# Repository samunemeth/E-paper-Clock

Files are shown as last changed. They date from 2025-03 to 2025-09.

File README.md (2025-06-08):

> [!IMPORTANT]
> More features are hopefully coming soon!
>
> This repository is not even close to being finished.
> I will try to include all the files and useful resources,
> but there are a lot, so it will take time.

# E-paper Clock 

This is an e-paper clock based on a *WeAct Studio 2.9" BW* display,
and a custom *Info Station V6* mainboard.

## Current functionality

The clock can connect to a local network to get the time hen powered on.
After this, and internal timer is calibrated to the current timezone.
The display is refreshed every minute. Between the refreshes, the *ESP32-C3*
and the display enters deep sleep to preserve battery power.

At set hours, the clock
will resync to a time server, and it will show the last resync.
The clock can also monitor it's battery level.
By pressing the update button, the display is kept awake to 
be able to remain connected to a computer, and receive and update easily.
Pressing the top button enables seconds mode, witch shows the seconds for a set
amount of time, or until the button is pressed again.

Settings can be configures easily in the [`settings.h`](src/settings.h) file.
Descriptions and recommendations are written next to important options.

> [!NOTE]
> I try to document the code as much as I can, but if you have any questions,
> feel free to contact me.

## PCB

The current version used by the codebase is **V6**.

The PCB can be found in the *mainboard* folder.
There are also gerber files, specifically exported for production with
[*JLCPCB*](https://jlcpcb.com/).
If you just want to look at the schematic, you can use the pdf.

> [!NOTE]
> The main branch is using the **V6** motherboard.
> If you want to use a **V2** motherboard, check out the dedicated branch.

## Setup

  - Install *PlatformIO*.
  - Clone this repository to your local machine.
  - Copy the [`src/wifi_secret.h.outline`](src/wifi_secret.h.outline) file,
    and rename it to `src/wifi_secret.h`.
  - Enter your WiFi SSID *(network name)* and password,
    replacing the placeholder values in `src/wifi_secret.h`.
  - Change your port settings in the [`platformio.ini`](platformio.ini) file.
    You can also use auto port detection on windows but *not* on linux.
  - Select the correct environment for uploading:
    - With `platformio.run --environment YourEnvironment` on command line.
    - By selecting the correct folder in *VSCode*.
  - I recommend using the default settings for the first upload.
    After that, you can change the settings in the
    [`settings.h`](src/settings.h) file by commenting or uncommenting
    definitions, or by changing values. A short explanation of options
    are included in the file.

## ToDo

**Implement**
  - Add charging detection.
  - Add stopper mode.
  - Show wifi strength at last sync.
  - Multiple WiFi connections.
    *[More Info](https://randomnerdtutorials.com/esp32-wifimulti/)*
  - Skip resync if the wifi times out.
  - Better fonts, for example *Roboto*.
  - Switch to using precise time.

**Ideas**
  - Add hibernation for night? *(Basically just a longer deep sleep at night.)*
  - Indicate potential drift based on time from last sync.

**Test**
  - Check SNTP time documentation, if it only gets time once.
  - Test the three different internal, and external oscillators.
    *[More Info](https://docs.espressif.com/projects/esp-idf/en/stable/esp32c3/api-reference/system/system_time.html)*
  - Test power consumption with different configurations.
  - Ways to connect to WiFi faster, like storing the channel number, or setting
  up a persistent wifi connection.
  - ***GPIO4 can and will fuck with you!***

**Document**
  - Document the telemetry collection server.
  - Document the font creation process.
  - Document assembly and schematics.
  - Document 3D printed parts.

## Regarding the display

### Differences

After ordering multiple display panels from the same
[AliExpress listing](https://www.aliexpress.com/item/1005004644515880.html?spm=a2g0o.order_list.order_list_main.89.31de1802V2DEme),
I received two different kinds of display modules.
from the outside they look almost identical, apart from the part number
on the display ribbon cable. The older ones are marked *FPC-A005*, while
the newer ones are marked *FPC-7519rev.b*.
The displays have the same [documentation provided by WeAct Studio](https://github.com/WeActStudio/WeActStudio.EpaperModule/blob/master/Doc/ZJY128296-029EAAMFGN.pdf).

As they are both copies of similar displays, we have to take these numbers
with a grain of salt. The old one seems to be a copy (and simplification)
of a 3 color display, while the new one seems to be a copy (and again, 
simplification) of this
[Waveshare panel](https://www.waveshare.com/product/2.9inch-e-paper-module.htm).
While the old display lacks the third color, the new one is missing the
gray levels. *(Or at least, I could not get it to work...)*

After powering the on, the difference is obvious: the refresh times.
While the old display takes  around 4s to do a full refresh, the new one only
takes around 2s, and does not blink as much, making it a lot less distracting.
The new display does seem to loose quality faster when doing partial
refreshes.
For these reasons, I prefer partial refreshes on the old, and
full refreshes on the new display.

The new display also goes to hibernation, while the old one seems
to consume around 1mA. I am still testing this aspect.

Despite these differences, the communication and setup for the displays
are the same, they are a drop-in replacement for each other.

### Display health

As *WeAct Studio* does not provide any information regarding display health,
I will be referencing [Waveshare's display health information](https://www.waveshare.com/wiki/2.9inch_e-Paper_Module_Manual#Precautions)
for a very similar display.

It suggest full refreshing every *"several"* partial refreshes.
As *several* is not too exact, I would go with 5-10 partial refreshes for a
full refresh
However, after running one of the older displays for around 2 months with
only fast refreshes, I do not see any mayor degradation.

It also recommends a refresh interval of *"at least 180s"*.
That will not happen for a clock of course, but again I do not see
any particular reason this should affect the display in any negative way.

They also suggest powering down the display, or putting it in deep sleep.
This of course is done as soon as possible, and is an understandable
requirement.

## Design Choices

### Global SPI Port Remapping

As the default SPI pins on the *ESP32-C3 Supermini* are located in
locations unsuitable for this project, as they use important pins in
the RTC pin domain. These are the pins that can be used for wakeup
from deep sleep, and the pins that can be held during deep sleep.
As these pins are needed for other applications, we need to remap the
SPI pins to less important ones.

The port remapping is done by modifying the default `pins_arduino.h`
configuration file. Thankfully this can be done on a per-project basis.
The location of the configuration file is changed to the local one with
the  `board_build.variants_dir = variants` option.

To view the new pin configuration, check out the file:
[`pins_arduino.h`](variants/lolin_c3_mini/pins_arduino.h).

### Modes

Modes are stored in a `uint8_t`, and have constants with their names
and a `*_MODE` suffix.

| Mode Name: | NULL | RESET | NORMAL | RESYNC | SECONDS | STOPPER | UPDATE | CRITICAL |
| ---: | :---: | :---: | :---: | :---: | :---: | :---: | :---: | :---: |
| Decimal Value: | 0 | 1 | 2 | 4 | 8 | 16 | 32 | 64 |
| Bit shifted Value: | 0 | 1 << 0 | 1 << 1 | 1 << 2 | 1 << 3 | 1 << 4 | 1 << 5 | 1 << 6 |

### Timer Choice

The project is currently uses the *external* oscillator over the default
*RC* oscillator, or the internal *8MD256* oscillator.
This is presumably the middle gorund considering both
accuracy and power consumption.
The compromises are not yet fully clear to me,
*further testing and investigation is required*.

## Useful Resources

  - Purchase display:
    [AliExpress](https://www.aliexpress.com/item/1005004644515880.html?spm=a2g0o.order_list.order_list_main.89.31de1802V2DEme).
  - Library used for the display:
    [GxEPD2](https://github.com/ZinggJM/GxEPD2)
  - Sleep modes on the *ESP32-C3*:
    [Espressif Documentation](https://docs.espressif.com/projects/esp-idf/en/v5.4/esp32c3/api-reference/system/sleep_modes.html).
  - GPIO documentation:
    [Espressif Documentation](https://docs.espressif.com/projects/esp-idf/en/v5.1.4/esp32c3/api-reference/peripherals/gpio.html).
  - Showcasing the display and library:
    [Video](https://youtu.be/KZGjsC-JkR8?si=c3sMc7xT4hFs9A2L).
    And the code they used:
    [GitHub](https://github.com/devtales-official/screen-test/tree/main/devtales_screentest_ep2).
  - Generating new fonts:
    [Adafruit Documentation](https://learn.adafruit.com/adafruit-gfx-graphics-library/using-fonts).
    *(tl;dr: You pretty much must do this on linux.)*
  - How to remap global SPI ports:
    [Arduino Forum Thread](https://forum.arduino.cc/t/understanding-spi-pin-remapping-for-gxepd2-on-a-esp32-c3-mini/1065982).
    *(I looked 3 hours for this.)*
  - Advanced deep sleep wakeup functionality:
    [Espressif Documentation](https://docs.espressif.com/projects/esp-idf/en/stable/esp32c3/api-guides/deep-sleep-stub.html).
  - Deep sleep wakeup with gpio:
    [StackOverflow](https://stackoverflow.com/questions/76823215/deep-sleep-with-ext0-or-ext1-on-esp32-c3-mini-1).
  - Holding pins in deep sleep:
    [Reddit](https://www.reddit.com/r/esp32/comments/1dhh5ez/esp32c3_pin_goes_high_on_deep_sleep/).
  - ADC accuracy:
    [Link Tree](https://www.esp32.com/viewtopic.php?t=23902).
  - Built in adc calibration:
    [Reddit](https://www.reddit.com/r/esp32/comments/1dybanl/measuring_battery_levels/).
  - Estimating battery percentage from voltage:
    [Desmos](https://www.desmos.com/calculator/tfllnkhdcv),
    [Reference Data](https://blog.ampow.com/lipo-voltage-chart/).
  - Rebooting with persistent RTC memory:
    [Reddit](https://www.reddit.com/r/esp32/comments/qokk1z/reboot_without_losing_rtc_variables/).
  - ESP-C3 supermini pinout:
    [Arduino Forum Thread](https://forum.arduino.cc/t/esp32-c3-supermini-pinout/1189850/23).
  - Sub sleep levels:
    [Espressif Documentation](https://docs.espressif.com/projects/esp-idf/en/stable/esp32c3/api-reference/system/sleep_modes.html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).
  - Optimization:
    [Espressif Documentation](https://docs.espressif.com/projects/esp-idf/en/v5.2.5/esp32c3/api-guides/performance/speed.html)
  - Display driver:
    [Data Sheet](https://mikroshop.ch/pdf/EPaper29.pdf)
  - Online XBM editor:
    [Webpage](https://xbm.jazzychad.net)

## Ports, Future Updates

The display could be reasonably used with *Esphome*.
The configuration however is quite difficult, and the power efficiency will 
definitely be worse. I do not think I will be attempting to port it.
I already have code for a [similar project](#related-projects).

## Related Projects

The mainboard is borrowed from *Weather Station V1*.
The only hardware difference is the display,
as that project uses the 3 color version.
The software however is completely different, as that project uses *Esphome*.

After designing the new mainboard, I will be publishing more information
and configuration regarding that project, in a separate repo.

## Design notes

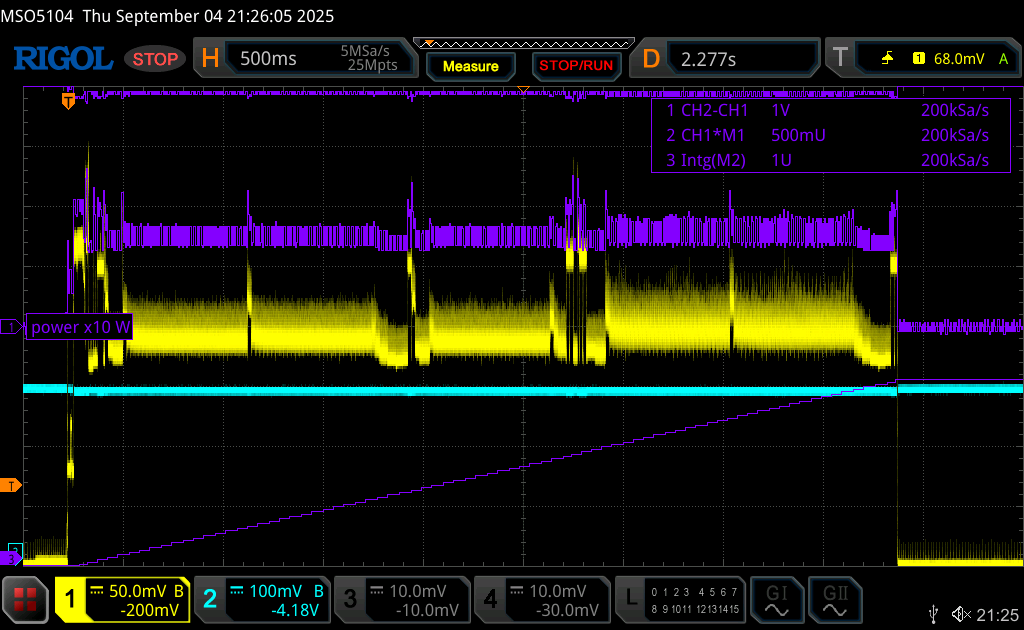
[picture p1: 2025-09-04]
collected-data/new-display-clear-refresh/graph.png

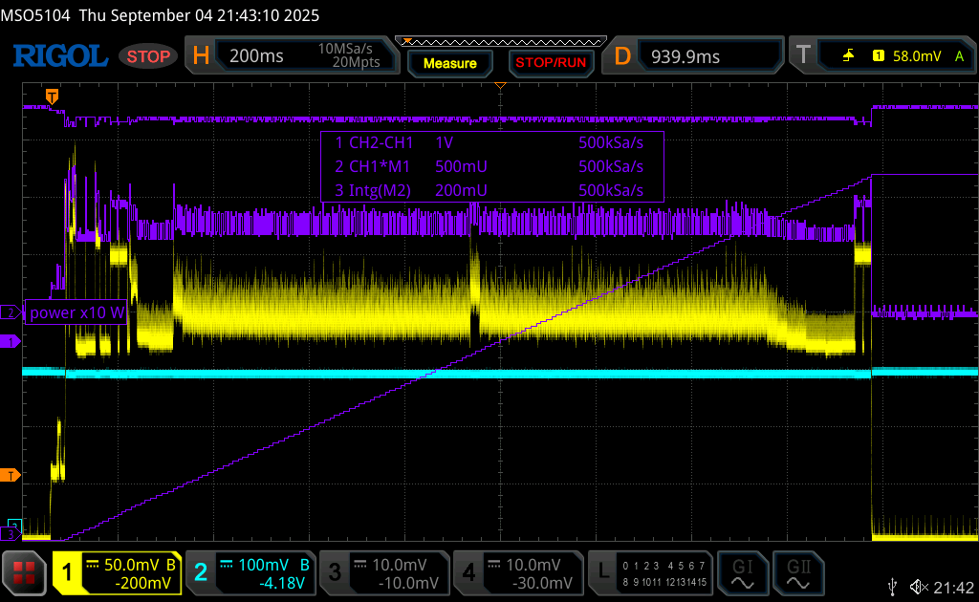
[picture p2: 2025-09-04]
collected-data/new-display-full-refresh/graph.png

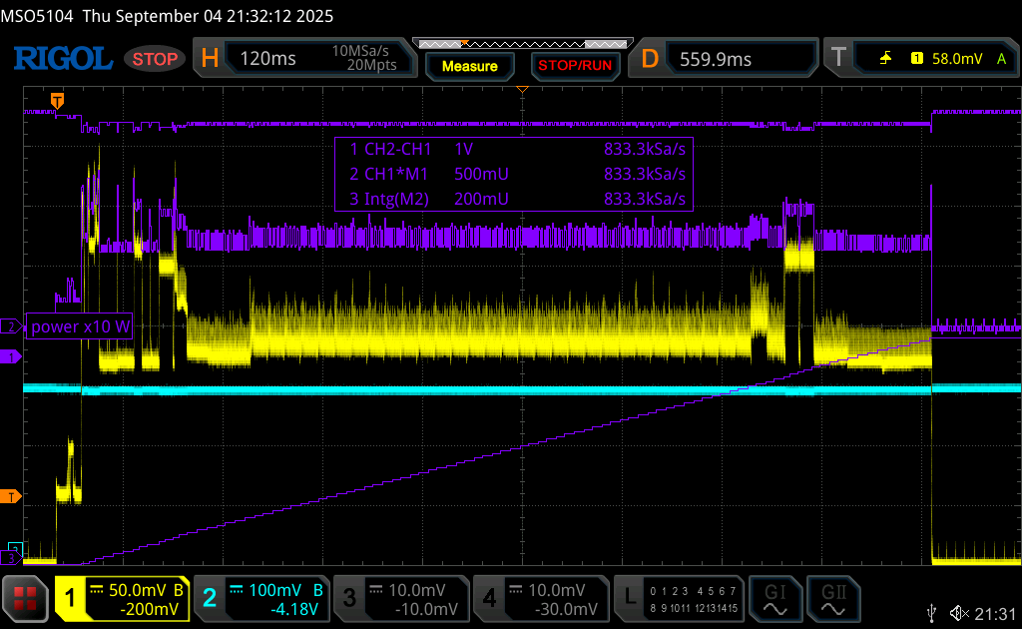
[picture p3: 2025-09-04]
collected-data/new-display-partial-refresh/graph.png

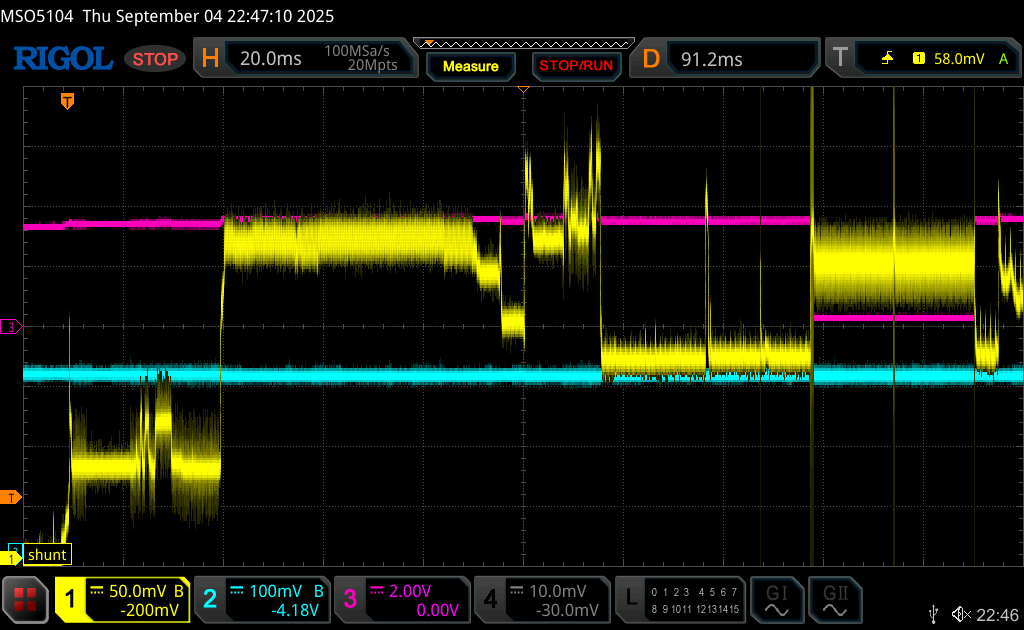
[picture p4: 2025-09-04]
collected-data/cs-signal.png

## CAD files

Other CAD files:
collected-data/new-display-clear-refresh/setup.stp
collected-data/new-display-full-refresh/setup.stp
collected-data/new-display-partial-refresh/setup.stp
collected-data/old-display-partial-refresh/setup.stp

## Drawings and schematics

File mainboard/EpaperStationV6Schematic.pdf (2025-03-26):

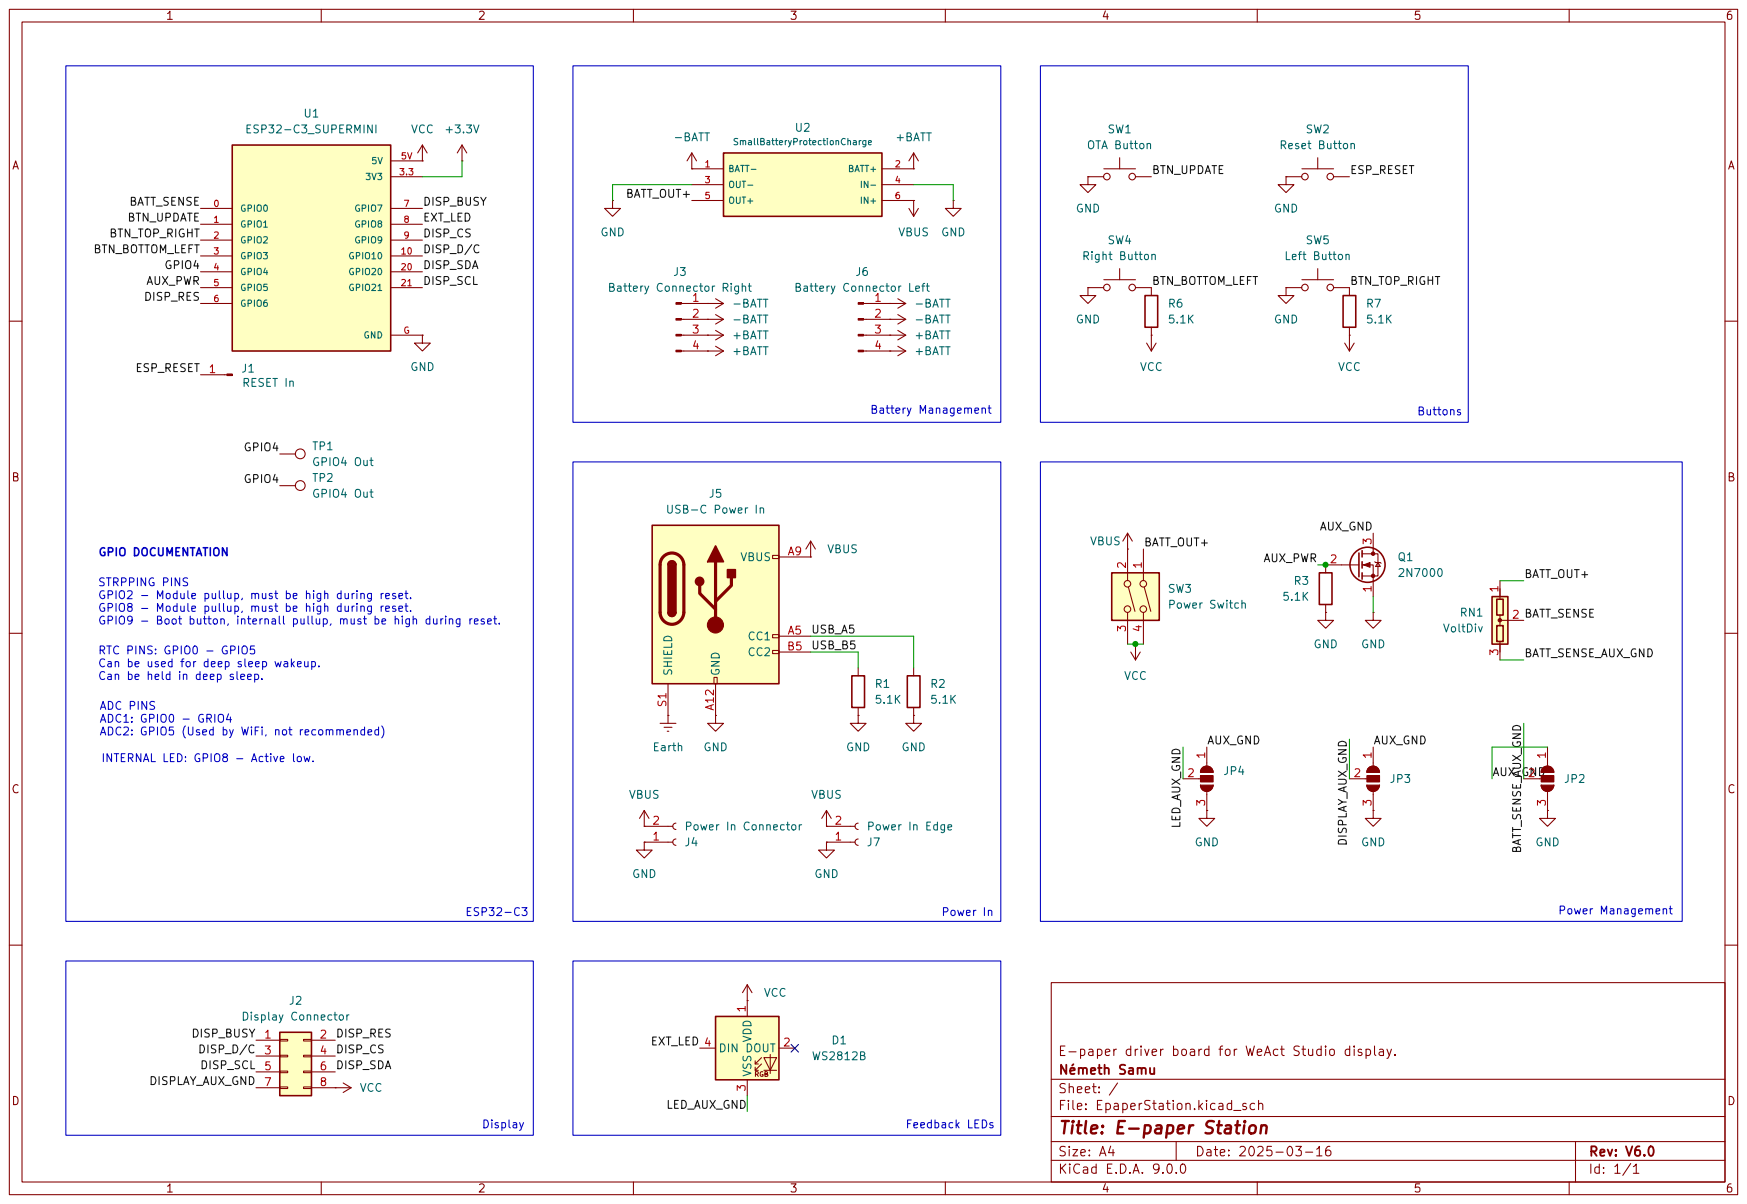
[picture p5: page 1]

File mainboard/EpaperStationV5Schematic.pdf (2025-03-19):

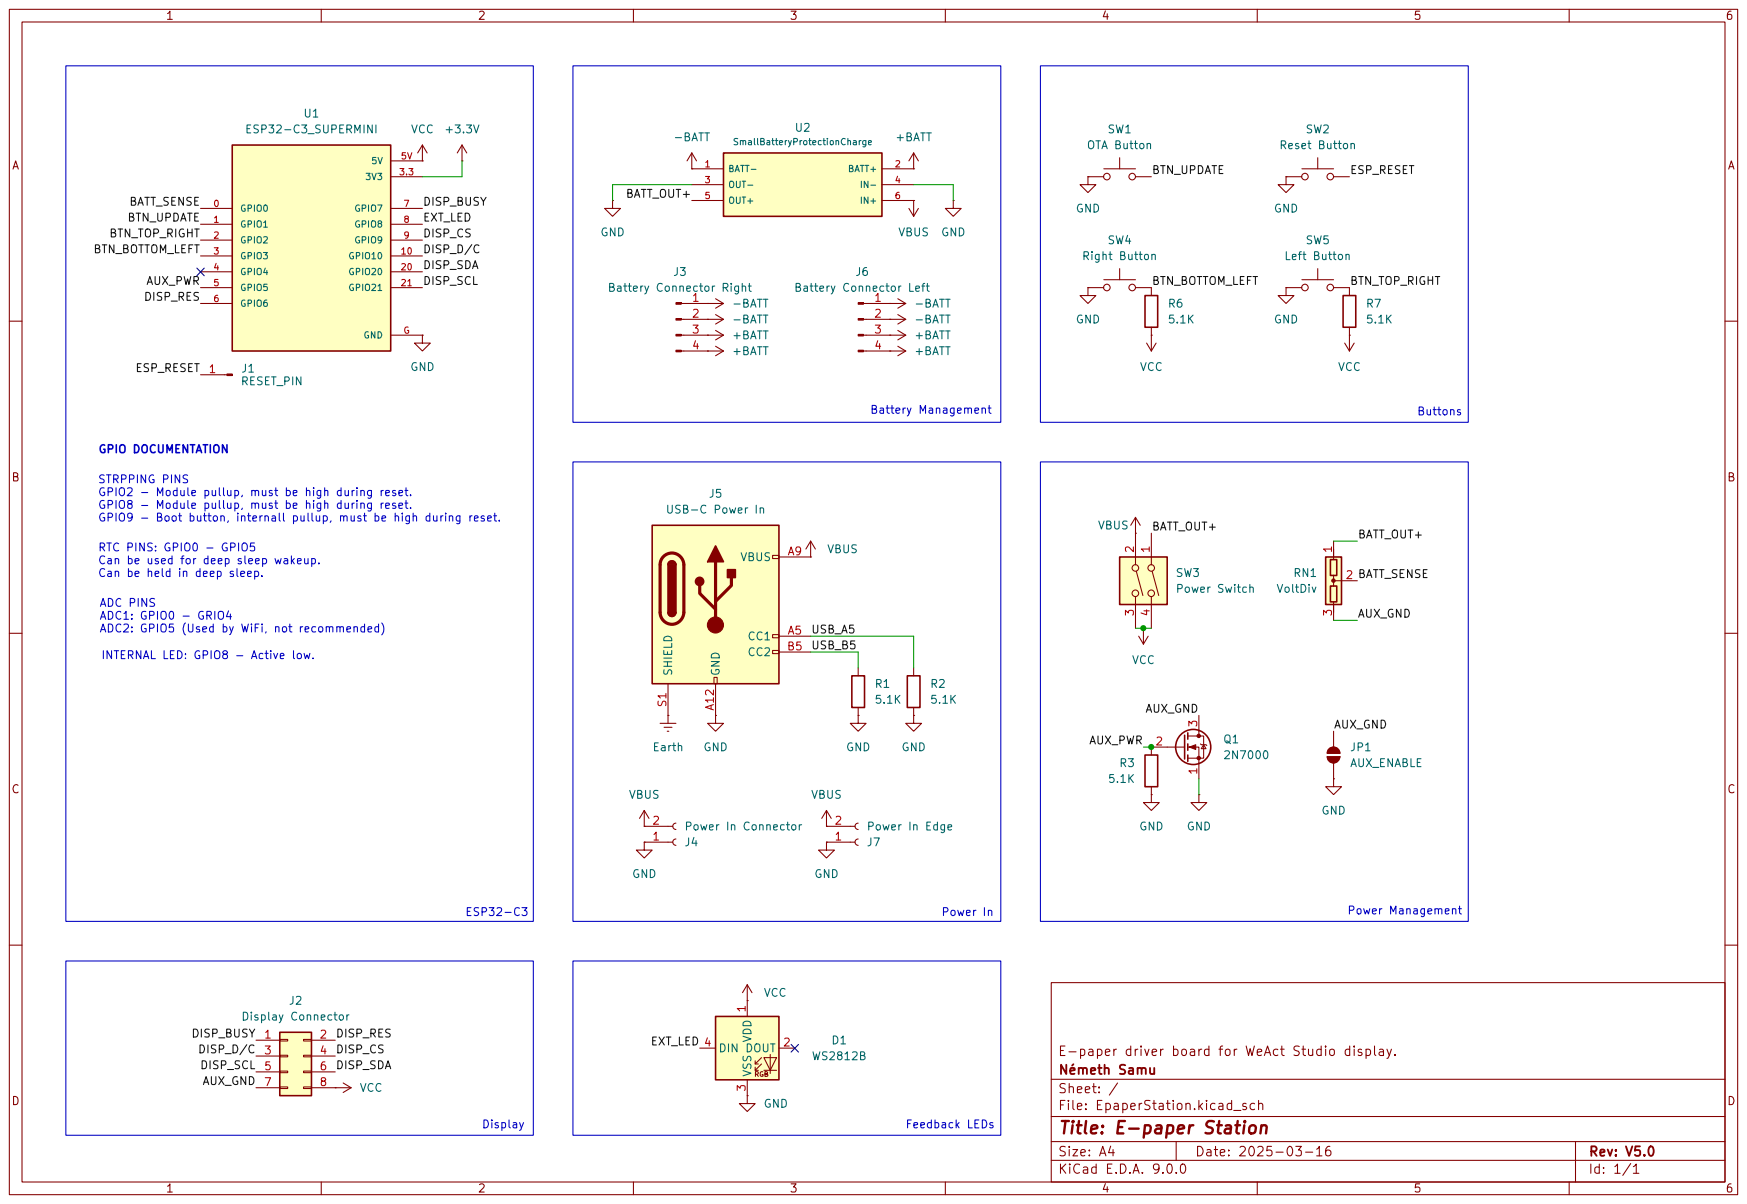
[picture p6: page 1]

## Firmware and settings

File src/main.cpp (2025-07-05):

// --- GxEPD2 Settings ---
#define ENABLE_GxEPD2_GFX 0


// --- Libraries ---
#include <Arduino.h>
#include <WiFi.h>
#include <HTTPClient.h>

#include <esp_sntp.h>
#include <esp_adc_cal.h>


// --- Settings and Pins ---
#include "settings.h"
#include "pins.h"
#include "wifi_secret.h"


// --- Components ---
#include "display_helper/display_helper.h"


// --- Calculated Constants ---
const TickType_t loop_tick_delay = LOOP_WAIT_TIME / portTICK_PERIOD_MS;


// --- Mode Numbering ---
#define NULL_MODE     0b00000000
#define RESET_MODE    0b00000001
#define NORMAL_MODE   0b00000010
#define RESYNC_MODE   0b00000100
#define SECONDS_MODE  0b00001000
#define STOPPER_MODE  0b00010000
#define UPDATE_MODE   0b00100000
#define CRITICAL_MODE 0b01000000

// --- Global Variables ---

// Mode variables, and counters in RTC memory
uint8_t RTC_NOINIT_ATTR desired_mode = NULL_MODE;
uint8_t RTC_NOINIT_ATTR mode = NULL_MODE;
uint32_t RTC_NOINIT_ATTR boot_num = 0;

// Last sync variables in RTC memory
uint8_t RTC_NOINIT_ATTR last_sync_minute;
uint8_t RTC_NOINIT_ATTR last_sync_hour;
char RTC_NOINIT_ATTR strf_last_sync_hour_buf[3];
char RTC_NOINIT_ATTR strf_last_sync_minute_buf[3];

// Time shift compensation variables in RTC memory
int32_t RTC_NOINIT_ATTR time_shift_average;
int32_t RTC_NOINIT_ATTR time_shift_samples;

int32_t RTC_NOINIT_ATTR time_correction_step;

int32_t RTC_NOINIT_ATTR time_deviation_average;
int32_t RTC_NOINIT_ATTR time_deviation_samples;

// Battery variable in RTC memory
char RTC_NOINIT_ATTR strf_battery_value_buf[8];
uint8_t RTC_NOINIT_ATTR battery_status;

// Wifi strength in RTC memory
int8_t RTC_NOINIT_ATTR wifi_strength;

// Time related variables
time_t now;
struct tm timeinfo;
struct timeval tv_now;

// String buffers
char strf_hour_buf[3];
char strf_minute_buf[3];
char strf_date_buf[16];

// Loop status
bool loop_running;
bool fast_refresh;


// --- Function Declarations ---


// Interrupt functions.
void IRAM_ATTR intUpdateMode();
void IRAM_ATTR intSecondsMode();
void IRAM_ATTR intNormalMode();
void IRAM_ATTR intLoopStop();
void IRAM_ATTR sntpSyncCallback(timeval *tv);

// Time related functions.
void getTime();
void formatStrings();
void configureTimeZone();
void adjustTime(int32_t offset);


// --- Code ---
void setup() {


    // --- Getting the Mode ---


    /*     
        To request modes, and store previous modes, and date from before resets,
        RTC FAST memory is used. Variables labelled with `RTC_NOINIT_ATTR` are
        store in RTC FAST memory, and as the "NOINIT" port suggest, are not
        cleared on resets.
        (As opposed to `RTC_DATA_ATTR`, witch only persists after deep sleep.)

        To filter mangled data after a power on reset - or crash -
        the variables are cleared unless a soft reset or wakeup occurred.
    */
    
    // Get the reason of the reset.
    const esp_reset_reason_t reset_cause = esp_reset_reason();

    // If we were not soft reset, or woken up from deep sleep, we have to wipe some variables.
    if ((reset_cause != ESP_RST_DEEPSLEEP) && (reset_cause != ESP_RST_SW)) {

        // Clear persistent variables.
        desired_mode = RESET_MODE;
        mode = NULL_MODE;
        boot_num = 0;

        time_shift_average = 0;
        time_shift_samples = 0;
        time_correction_step = 0;
        time_deviation_average = 0;
        time_deviation_samples = 0;
        
        /*
            As there will be a resync after a hard reset, there is no need to
            initialize the following variables:

            strf_last_sync_hour_buf;
            strf_last_sync_minute_buf;
            last_sync_hour;
            last_sync_minute;
            strf_battery_value_buf;
            battery_status;
            wifi_strength;
        */

    }

    // Rotate mode variable to last mode.
    const uint8_t last_mode = mode;

    // Check if we have a valid desired mode.
    if (desired_mode & (NORMAL_MODE + UPDATE_MODE + SECONDS_MODE + RESET_MODE)) {

        // Set that as our current mode.
        mode = desired_mode;

    } else {

        // If we do not have a valid desired mode, just clear the variable.
        mode = NULL_MODE;

    }

    // Clear the desired mode
    desired_mode = NULL_MODE;
    
    // Next, we may need these inputs.
    pinMode(OTA_SW_PIN, INPUT_PULLUP);
    pinMode(BTN_TOP_PIN, INPUT_PULLUP);

    // If we have woken up from deep sleep, investigate the cause.
    if (reset_cause == ESP_RST_DEEPSLEEP && mode == NULL_MODE) {

        // Get the wakeup cause.
        const esp_sleep_wakeup_cause_t wakeup_cause = esp_sleep_get_wakeup_cause();

        // If the timer triggered the wakeup, we can be sure that we are either in normal mode.
        if ( wakeup_cause == ESP_SLEEP_WAKEUP_TIMER ) { mode = NORMAL_MODE; }

        // Here, we can check for a GPIO wakeup, if there is still no mode defined.
        else if ( wakeup_cause == ESP_SLEEP_WAKEUP_GPIO ) {

            // We can read the GPIO pins connected to the buttons.
            // As the ESP reboots pretty fast, if the press is average length, it will still be pressed here.
            // If the last mode was the same, do not enter update mode again, as this was a button press to exit.
            // Update mode has a higher priority, we will check that first.

            if      ( (digitalRead(OTA_SW_PIN) == LOW) && (last_mode != UPDATE_MODE) ) { mode = UPDATE_MODE;  }
            else if ( digitalRead(BTN_TOP_PIN) == LOW )                                { mode = SECONDS_MODE; }

        }

    }

    // If we are in normal mode, we may need to do a resync.
    if ((mode == NORMAL_MODE) && (boot_num % RESYNC_EVERY == 0)) { mode = RESYNC_MODE; }

    // If we are not in any mode yet, just say we were in a reset.
    // This should not be strictly necessary, but it's a good catch all.
    // (An error could occur if we soft reset without a valid desired mode.)
    if (mode == NULL_MODE) { mode = RESET_MODE; }


    // --- Powering Up, Initializing, Detecting Mode Modes ---


    // Adjust the time with the correction value.
    adjustTime(time_correction_step);

    // Setting up the AUX pin for a possible use.
    pinMode(AUX_PWR_PIN, OUTPUT);

    // Turn on aux power if display need it.
    #if defined(AUX_FOR_DISP)
        digitalWrite(AUX_PWR_PIN, HIGH);
    #endif /* AUX_FOR_DISP */

    // If we are not in update mode, we can attach the interrupt to the update button.
    if (mode != UPDATE_MODE) {
        attachInterrupt(digitalPinToInterrupt(OTA_SW_PIN), intUpdateMode, FALLING);
    }

    // If we are in normal mode, we can attach the interrupt to the top button.
    if (mode == NORMAL_MODE) {
        attachInterrupt(digitalPinToInterrupt(BTN_TOP_PIN), intSecondsMode, FALLING);
    }

    // Measure battery voltage if needed.
    if (boot_num % BATT_SENSE_EVERY == 0) {

        // Turn on the aux power if the voltage divider needs it.
        #if defined(AUX_FOR_BATT_SENSE)
            digitalWrite(AUX_PWR_PIN, HIGH);
        #endif /* AUX_FOR_BATT_SENSE */

        // Set the battery voltage pin to input.
        pinMode(BATT_SENSE_PIN, INPUT);

        // Get raw measurement with oversampling.
        uint32_t battery_raw;
        for (uint8_t i = 0; i < ADC_OVER_SAMPLE_COUNT; i++) {
            battery_raw += analogRead(BATT_SENSE_PIN);
        }
        battery_raw = battery_raw / ADC_OVER_SAMPLE_COUNT;

        // Calibrate the battery voltage reading.
        esp_adc_cal_characteristics_t adc_chars;
        esp_adc_cal_characterize(ADC_UNIT_1, ADC_ATTEN_DB_11, ADC_WIDTH_BIT_12, 1100, &adc_chars);
        uint32_t battery_voltage = esp_adc_cal_raw_to_voltage(battery_raw, &adc_chars) * ADC_FACTOR;

        // Turn off the aux power if display does not need it.
        #if !defined(AUX_FOR_DISP)
            digitalWrite(AUX_PWR_PIN, LOW);
        #endif /* !AUX_FOR_DISP */

        // Detect critically low battery level, switch to critical mode.
        if (battery_voltage <= CRITICAL_BATTERY_LEVEL) {
            mode = CRITICAL_MODE;
        }

        // Calculate battery percent based on an approximation. 
        uint8_t battery_percent;
        if (battery_voltage >= (4200 - FULL_BATTERY_TOLERANCE)) {
            battery_percent = 100;
        } else if (battery_voltage >= 3870) {
            battery_percent = round(120 * ((float)battery_voltage/1000) - 404);
        } else if (battery_voltage > 3300) {
            battery_percent = round(113 / (1 + exp(46.3 - 12 * ((float)battery_voltage/1000))));
        } else {
            battery_percent = 0;
        }

        // Round, and convert to a string.
        sprintf(strf_battery_value_buf, "%d%%", battery_percent);

        // Set battery status based on level.
        if (battery_percent < 25) {
            battery_status = 0;
        } else if (battery_percent < 50) {
            battery_status = 1;
        } else if (battery_percent < 75) {
            battery_status = 2;
        } else {
            battery_status = 3;
        }

    }

    // Configure the time zone, regardless of the mode. We have to do it either way.
    configureTimeZone();

    // The order of operations is intentional.
    // This way the display can initialize while we read sensors.


    // --- Blocking Modes ---


    // Initialize the display.
    // If we are in RESET mode, we have to wipe the screen.
    displayInit(mode & (CRITICAL_MODE + RESET_MODE));

    // If we are in critical mode, we need to display a warning message, and shut down the processor.
    if (mode == CRITICAL_MODE) {

        // A full refresh may be needed.
        #if !defined(AUX_FOR_DISP) && defined(PREFER_FAST_REFRESH)
            fast_refresh = true;
        #else
            fast_refresh = false;
        #endif /* !AUX_FOR_DISP && PREFER_FAST_REFRESH */

        // Draw to display
        displayStartDraw(/*fast=*/ fast_refresh);

        displayRenderCriticalMessage();

        displayEndDraw();

        // Turn off the display and auxiliary power. We do not need them any more.
        displayHibernate();
        digitalWrite(AUX_PWR_PIN, LOW);

        // Disable wakeup sources
        esp_sleep_disable_wakeup_source(ESP_SLEEP_WAKEUP_ALL);

        // Go into INDEFINITE deep sleep. (Basically shut down.)
        esp_deep_sleep_start();

        // Nothing is run after this.
        
    }

    // If we are in update mode, we basically have to stall the processor.
    if (mode == UPDATE_MODE) {

        // Turn on aux power for external led if needed.
        #if defined(AUX_FOR_EXT_LED)
            digitalWrite(AUX_PWR_PIN, HIGH);
        #endif /* AUX_FOR_EXT_LED */
  
        // Turn on led
        pinMode(EXT_LED_PIN, OUTPUT);
        digitalWrite(EXT_LED_PIN, LOW);

        // Turn the update button into a button returning to normal mode.
        attachInterrupt(digitalPinToInterrupt(OTA_SW_PIN), intNormalMode, FALLING);

        // A full refresh may be needed.
        #if !defined(AUX_FOR_DISP) && defined(PREFER_FAST_REFRESH)
            fast_refresh = true;
        #else
            fast_refresh = false;
        #endif /* !AUX_FOR_DISP && PREFER_FAST_REFRESH */
        
        // Draw to display
        displayStartDraw(/*fast=*/ fast_refresh);
        
        displayRenderUpdateMessage();

        displayEndDraw();

        // Turn off the display and auxiliary power. We do not need them any more.
        displayHibernate();
        digitalWrite(AUX_PWR_PIN, LOW);

        // Block all other tasks.
        for (;;) vTaskDelay(loop_tick_delay);

        // Nothing is run after this.

    }


    // --- Running Modes ---

 
    // If we are in RESET mode, the clock may not be set yet. Instead of a time, 
    // we display a message, or just clear the display.
    if (mode == RESET_MODE) {
        
        displayStartDraw(/*fast=*/ true);
        displayEndDraw();

    }

    // In RESET and RESYNC mode, we need to connect to a wifi network, and sync with and SNTP server.
    if (mode & (RESYNC_MODE + RESET_MODE)) {
        
        // Skip the sync for development purposes.
        #if !defined(SKIP_SYNC)

        // Get precise time.
        gettimeofday(&tv_now, NULL);
        int64_t time_before_ms = (int64_t)tv_now.tv_sec * (int64_t)1000 + ((int64_t)tv_now.tv_usec / (int64_t)1000);

        // Try to make and educated guess of the sync time.
        int64_t time_waiting_ms = 0;

        // Set up variable for potential interrupt.
        loop_running = true;
        
        // Configure SNTP time sync.
        sntp_setoperatingmode(SNTP_SYNC_MODE_IMMED);
        sntp_setservername(1, SNTP_1);
        sntp_setservername(2, SNTP_2);
        sntp_set_time_sync_notification_cb(sntpSyncCallback);
        sntp_init();
        
        // Set up WiFi
        WiFi.persistent(false);
        WiFi.mode(WIFI_STA);
        WiFi.begin(ssid, password);

        // Configure the time zone again, as the settings get lost here.
        configureTimeZone();
        
        // Wait for WiFi to connect, and time to sync.
        do {
            getTime();
            vTaskDelay(loop_tick_delay);
            time_waiting_ms += LOOP_WAIT_TIME;
        } while (loop_running || (timeinfo.tm_year < 100));
        loop_running = true;
        
        // Wait a bit to allow the clock to actually sync.
        vTaskDelay(loop_tick_delay);
        time_waiting_ms += LOOP_WAIT_TIME;
        
        // Get precise time.
        gettimeofday(&tv_now, NULL);
        int64_t time_after_ms = (int64_t)tv_now.tv_sec * (int64_t)1000 + ((int64_t)tv_now.tv_usec / (int64_t)1000);
        
        // Calculate the resulting time difference from the sync.
        int32_t time_deviation_ms = (int32_t)(time_after_ms - time_before_ms - time_waiting_ms);
        int32_t time_shift_ms = time_deviation_ms + time_shift_average;

        // Skip average calculation after reset, as the shift here can be chaotic.
        if (mode != RESET_MODE) {

            // Calculate new average time shift.
            int32_t time_shift_history_weight = 3; // Just an educated guess at this point!
            time_shift_average = (time_shift_ms + (time_shift_average * time_shift_history_weight)) / (time_shift_history_weight + (int32_t)1);
            time_shift_samples++;

            // Calculate the new time deviation.
            if (time_shift_samples > 1) {

                time_deviation_average = (abs(time_deviation_ms) + (time_deviation_average * time_deviation_samples)) / (time_deviation_samples + (int32_t)1);
                time_deviation_samples++;

            } else {

                time_deviation_ms = 0;

            }

            // Calculate the new time correction step size.
            time_correction_step = time_shift_average / (int32_t)RESYNC_EVERY;

        } else {

            // After a reset, time shift does not make sense.
            time_shift_ms = 0;
            time_deviation_ms = 0;

        }

        // Get wifi network strength.
        wifi_strength = WiFi.RSSI();

        // Make an HTTP POST request for data logging.
        #if defined(REPORT_TELEMETRY)

            /* 
                The buffer neds to be big enough to fit all the data.
                The size of the different data parts:
                    - Outline:              250
                    - UUID:                 36
                    - BatteryLevel:         4
                    - BootNum:              10
                    - currentMode:          3
                    - timeShift:            10
                    - timeShiftAverage:     10
                    - timeShiftSamples:     10
                    - syncDuration:         10
                    - wifiStrength:         4
                    - timeDeviation:        10
                    - timeDeviationAverage: 10
                    - timeDeviationSamples: 10
                Total:                      377
            */
            char strf_post_buf[380];

            // Fill the buffer with the formatted string.
            sprintf(strf_post_buf,
                "{"
                    "\"uuid\":\"%s\","
                    "\"bootNum\":\"%d\","
                    "\"currentMode\":\"%d\","
                    "\"batteryLevel\":\"%s\","
                    "\"wifiStrength\":\"%d\","
                    "\"syncDuration\":\"%d\","
                    "\"timeShift\":\"%d\","
                    "\"timeShiftAverage\":\"%d\","
                    "\"timeShiftSamples\":\"%d\","
                    "\"timeDeviation\":\"%d\","
                    "\"timeDeviationAverage\":\"%d\","
                    "\"timeDeviationSamples\":\"%d\""
                "}",
                uuid, boot_num, mode, strf_battery_value_buf, wifi_strength,
                (int32_t)time_waiting_ms,
                time_shift_ms, time_shift_average, time_shift_samples,
                time_deviation_ms, time_deviation_average, time_deviation_samples
            );

            // Create an http client.
            HTTPClient http;

            // Configure url and data to send.
            http.begin(reportingUrl);
            http.addHeader("Content-Type", "application/json");
            int httpRes = http.POST(strf_post_buf);

            // Close the connection.
            http.end();

        #endif
        
        // Turn off the Wifi
        WiFi.mode(WIFI_OFF);
        
        #endif /* !SKIP_SYNC */

        // Set the last sync times
        last_sync_hour = timeinfo.tm_hour;
        last_sync_minute = timeinfo.tm_min;

        // Update the strings
        sprintf(strf_last_sync_hour_buf, "%02d", last_sync_hour);
        sprintf(strf_last_sync_minute_buf, "%02d", last_sync_minute);

    }

    // Display seconds in the seconds mode.
    if (mode == SECONDS_MODE) {

        // A full refresh may be required first.
        #if defined(AUX_FOR_DISP)
            fast_refresh = false;
        #else
            fast_refresh = true;
        #endif /* AUX_FOR_DISP */
        
        // Loop and print seconds
        loop_running = true;
        uint8_t last_second = timeinfo.tm_sec;
        for (uint8_t i = 0; i < MAX_DISPLAYED_SECONDS; i++) {

            if (i == 2) {

                // Attach a loop stopping interrupt to the button.
                // This is done here to mitigate the issue of the seconds mode instantly quitting
                // when the button is pressed for a bit too long.
                attachInterrupt(digitalPinToInterrupt(BTN_TOP_PIN), intLoopStop, FALLING);

            }
            
            // Format time for display
            getTime();
            formatStrings();
            
            // Print the time and seconds to the display
            displayStartDraw(/*fast=*/ fast_refresh);
            fast_refresh = true;
            
            displayRenderBorders();
            displayRenderStatusBar(strf_battery_value_buf, strf_last_sync_hour_buf, strf_last_sync_minute_buf, battery_status);
            displayRenderTime(strf_hour_buf, strf_minute_buf);
            displayRenderDate(strf_date_buf);
            displayRenderSecond(timeinfo.tm_sec);
            
            displayEndDraw();

            do {
                getTime();
                vTaskDelay(loop_tick_delay);
            } while (timeinfo.tm_sec == last_second);
            
            last_second = timeinfo.tm_sec;

            if (!loop_running) break;

        }
        
        // Detach the interrupt and attach the original one.
        detachInterrupt(digitalPinToInterrupt(BTN_TOP_PIN));

        // Reset the variable.
        loop_running = true;

        // Clear the seconds with the final render
        goto finalRender;

    };

    // If we are really close to the minute, wait for it.
    // In other cases, we will just wake up before it.
    do {
        getTime();
        vTaskDelay(loop_tick_delay);
    } while (timeinfo.tm_sec > (59 - OMIT_SLEEP));

    // Format time for display
    formatStrings();
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
void loop() {};


// --- Function Definitions ---


// --- Interrupt Functions ---

void IRAM_ATTR intUpdateMode() {

    // Set desired mode to update mode.
    desired_mode = UPDATE_MODE;

    // Restart.
    esp_restart();

}

void IRAM_ATTR intSecondsMode() {

    // Set desired mode to seconds mode.
    desired_mode = SECONDS_MODE;

    // Restart.
    esp_restart();

}

void IRAM_ATTR intNormalMode() {

    // Set desired mode to normal mode.
    desired_mode = NORMAL_MODE;

    // Restart.
    esp_restart();

}

/// @brief Stops the current loop that the interrupt occurred in.
void IRAM_ATTR intLoopStop() {

    loop_running = false;

}

void IRAM_ATTR sntpSyncCallback(timeval *tv) {

    loop_running = false;

}


// --- Time related functions ---

/// @brief Get the time and local time, and save them to the global variables.
void getTime() {

    time(&now);
    localtime_r(&now, &timeinfo);

}

/// @brief Get the time, and set the timezone.
void configureTimeZone() {

    time(&now);
    setenv("TZ", TIMEZONE, 1);
    tzset();
    localtime_r(&now, &timeinfo);

}

void adjustTime(int32_t offset) {

    gettimeofday(&tv_now, NULL);
  
    int32_t total_usec = tv_now.tv_usec + (offset * 1000);
    if (total_usec >= 1000000) {
        tv_now.tv_sec += total_usec / 1000000;
        tv_now.tv_usec = total_usec % 1000000;
    } else if (total_usec < 0) {
        tv_now.tv_sec += (total_usec / 1000000) - 1;
        tv_now.tv_usec = 1000000 + (total_usec % 1000000);
    } else {
        tv_now.tv_usec = total_usec;
    }
  
    settimeofday(&tv_now, NULL);

}

/// @brief Update the global time string buffers with the corresponding values.
void formatStrings() {

    strftime(strf_hour_buf, sizeof(strf_hour_buf), "%H", &timeinfo);
    strftime(strf_minute_buf, sizeof(strf_minute_buf), "%M", &timeinfo);
    strftime(strf_date_buf, sizeof(strf_date_buf), "%F", &timeinfo);

}

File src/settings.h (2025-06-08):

// --- Behaviour ---

/* 
    Concerning the two different types of displays
    On the older, FPC-A005 B/W display:
      - Full refreshes take 4x the time and power of a partial refresh.
      - Display remains clear after multiple partial refreshes.
      - I recommend preferring fast refreshes, and full refreshing sparsely.
    On the newer, FPC-7519rev.b display:
      - Full refreshes take 2x the time and power of a partial refresh.
      - Display quality quickly degrades after a few partial refreshes.
      - I recommend preferring full refreshes, and full refreshing often.
    See README.md for more info!
*/

/* 
    Prefers partial refreshes over full refreshes.
    This does not affect normal mode!
    Normal mode is affected by the next option.
*/
//#define PREFER_FAST_REFRESH

/* 
    Do a full refresh in normal mode after this many boots.
    As in normal mode a boot occurs approximately every minute,
    this is basically in minutes.
*/
#define FULL_REFRESH_EVERY 5

/* 
    The following options have to be configured as to reflect
    the solder jumpers connected on the motherboard.
    Enable options where the jumper is connected to the aux power.
    The recommended configuration for the new display panel is shown below.
*/
//#define AUX_FOR_DISP
#define AUX_FOR_BATT_SENSE
#define AUX_FOR_EXT_LED

/* 
    Read the battery after this many boots.
    As in normal mode a boot occurs approximately every minute,
    this is basically in minutes.
*/
#define BATT_SENSE_EVERY 30

/* 
    Resync after this many boots.
    As in normal mode a boot occurs approximately every minute,
    this is basically in minutes.
*/
#define RESYNC_EVERY 240
//#define SKIP_SYNC

/* 
    Report telemetry data to a web server on resync.
    The url to report to can be configured in `wifi_secrets.h`
    This may consume a bit more power, but is really usefull for data logging.
*/
#define REPORT_TELEMETRY

// --- General Settings ---

#define LOOP_WAIT_TIME          20                             // The amount of time to wait im miliseconds per loop while waiting for something.

#define SNTP_1                  "0.pool.ntp.org"               // Primary SNTP server.
#define SNTP_2                  "1.pool.ntp.org"               // Secondary SNTP server.
#define TIMEZONE                "CET-1CEST,M3.5.0,M10.5.0/3"   // Time zone for the clock. Here I'm using Budapest time.

#define ADC_FACTOR              2                              // The factor to multiply the measured voltage with. Depends on the voltage divider.
#define ADC_OVER_SAMPLE_COUNT   16                             // How many times to sample and average the 

#define FULL_BATTERY_TOLERANCE  0                              // How much off can the battery voltage be from full, to be still considered as full.
#define CRITICAL_BATTERY_LEVEL  3500                           // Below this battery voltage, critical mode will be activated.

#define OMIT_SLEEP              1                              // If there are less than this many seconds to the minute, we wait instead of going to sleep.
#define SLEEP_MARGIN            100                            // The processor wakes this many milliseconds up before the designated update time.

#define MAX_DISPLAYED_SECONDS   10                             // The maximum number of seconds to count out in USER mode.

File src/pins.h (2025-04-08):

#ifndef USED_PINS
#define USED_PINS

// --- Pin Definitions ---

#define BATT_SENSE_PIN       0             // May need aux power
#define BATT_SENSE_PIN_NUM   GPIO_NUM_0

#define OTA_SW_PIN           1             // Active low
#define OTA_SW_PIN_NUM       GPIO_NUM_1

#define BTN_TOP_PIN          2             // Active low
#define BTN_TOP_PIN_NUM      GPIO_NUM_2

#define BTN_BOTTOM_PIN       3             // Active low
#define BTN_BOTTOM_PIN_NUM   GPIO_NUM_3

#define CHARGE_SENSE_PIN     4             // Active low
#define CHARGE_SENSE_PIN_NUM GPIO_NUM_4

#define AUX_PWR_PIN          5             // Active high
#define AUX_PWR_PIN_NUM      GPIO_NUM_5

#define DISP_RES_PIN         6
#define DISPLAY_BUSY_PIN     7

#define EXT_LED_PIN          8             // May need aux power, Internal and External LED

#define DISP_CS_PIN          9             // SS, GLOBALLY-SET
#define DISP_DC_PIN          10
#define DISP_MOSI_PIN        20            // MOSI, GLOBALLY-SET
#define DISP_SCL_PIN         21            // SCK, GLOBALLY-SET


#endif /* USED_PINS */

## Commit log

2025-03-14 Added back board environment
2025-03-15 Added ADC oversampling.
2025-03-15 Switched to internal ADC calibration.
2025-03-15 Added battery level calculation.
2025-03-15 Fixed battery percent bug
    [main.cpp]
2025-03-15 Added critical battery mode
2025-03-18 Added V4 mainboard schematic
2025-03-19 Added PCB related info and files
2025-03-26 Switched away from float where possible.
2025-03-30 Fixed clearing of string buffers
    [main.cpp]
2025-03-30 Temporarily removed DHCP time, as this caused longer reset times
    [main.cpp]
2025-04-08 Changed pin numbers
2025-04-11 Added missing boot counter incrementation
    [main.cpp]
2025-04-14 Started implementing temperature sensing.
2025-04-15 Revert "Started implementing temperature sensing."
    This reverts commit 0cb6d9b28d34349ad9a7d299e023947040796d72.
    [main.cpp, settings.h]
2025-04-15 Reworked mode naming and numbering
    [main.cpp, settings.h]
2025-04-20 Fixed incorrect last sync time
    [main.cpp]
2025-06-08 Removed time_shift calculation after reset.
    [main.cpp]
2025-06-09 Time deviation average and sample calculation.
2025-06-09 Shift deviation sampling by one compared to shift samples.
2025-09-04 Added data collected with an oscilloscope.
    [setup.stp]
